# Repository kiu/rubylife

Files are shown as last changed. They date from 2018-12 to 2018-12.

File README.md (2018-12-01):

# rubylife
Show the world your ruby affection and live the [#BadgeLife](https://twitter.com/search?q=%23badgelife)!

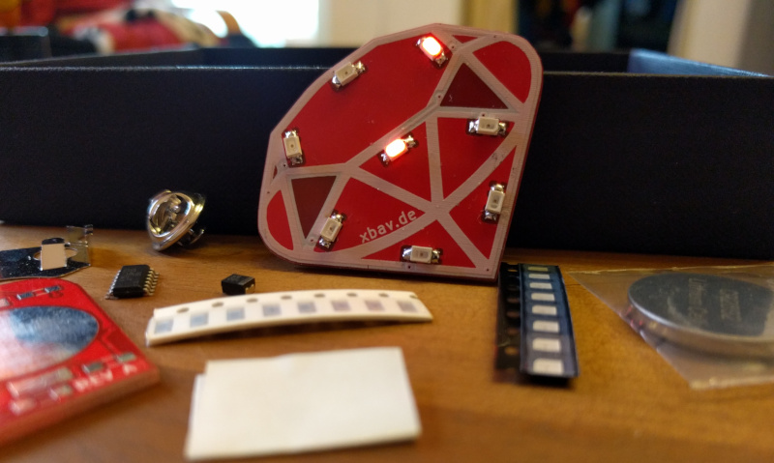
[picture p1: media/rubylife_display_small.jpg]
rubylife


# What does it do?
Besides being a stylish ruby pin, it can blink a few animations :)

# What do I need?
All you need is soldering gear (iron, tin, tweezers). Everything else is in the kit.

## I don't know how to solder!
It's easier than it looks, but a bit of help to kickstart your hardware adventure doesn't hurt. Ask your colleagues or friends for help. Or seek help in a [hackerspace](https://hackaday.io/hackerspaces) near you, they will love to teach you the ropes!

## Anything I need to know before I start?
Be aware that all parts - except for the resistors - have a polarity. Their orientation on the board is important.

Checkout this [reference](https://github.com/kiu/rubylife/raw/master/media/rubylife_polarity.jpg)!

## What is in the kit?

| Amount | Item |
| --- | ---- |
| 1 | Printed circuit board |
| 1 | Pre-programmed microcontroller |
| 8 | Red LED |
| 8 | Resistors |
| 1 | Capacitor |
| 1 | Battery Holder |
| 1 | Battery |
| 1 | Mounting pin |
| 1 | Glue dot |

A more detailed description can be found in the [Bill-Of-Materials](https://github.com/kiu/rubylife/raw/master/bom.pdf)

# I want to write my own software
Easy, but be aware that you need C skills to proceed :/

1. Setup an ATTiny development environment, e.g. [Atmel Studio](https://www.microchip.com/mplab/avr-support/atmel-studio-7)
2. Buy a hardware programmer. Make sure it supports TPI, e.g. [USBasp](https://www.fischl.de/usbasp/)
3. Hookup VCC, GND, TPIC, TPID and RES to your programmer and power it with 5 Volts
4. ???
5. Profit!

# Who created this?
[People](https://www.schoar.de/tinkering/rubylife/) from [xbAV](https://www.xbav.de) being passionate about hardware tinkering and the ruby community.

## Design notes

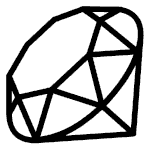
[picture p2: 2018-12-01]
hardware/kicad_mod_ruby.png

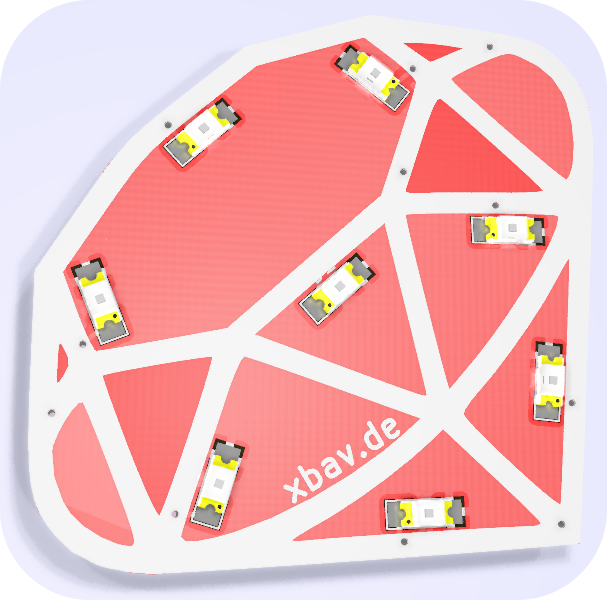
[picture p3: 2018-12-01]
hardware/kicad_rubylife_render_front.png

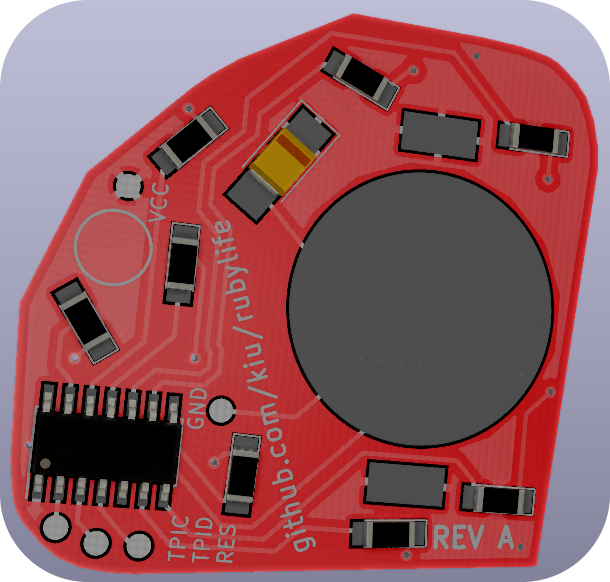
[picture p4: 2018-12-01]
hardware/kicad_rubylife_render_back.png

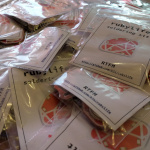
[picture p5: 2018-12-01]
media/rubylife_kit_pile_150x150.jpg

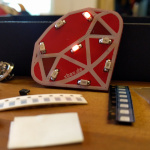
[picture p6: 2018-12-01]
media/rubylife_display_150x150.jpg

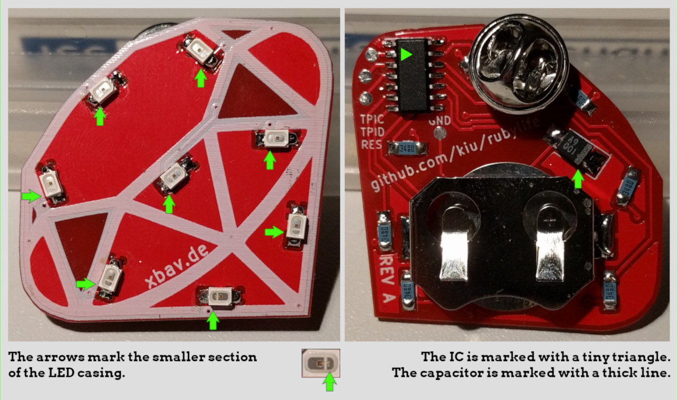
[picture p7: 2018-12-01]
media/rubylife_polarity.jpg

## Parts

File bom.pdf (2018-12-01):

BOM

Page 1

Symbol | Description | Req | +VAT | Price | Price (sum) | Price | Price (sum) | Provider | ID
| | | | MOQ 100 | | MOQ 50
U1 | ATTINY20 SOIC-14 | 1 | 19 | 0,41 € | 0,48 € | 0,44 € | 0,52 € | http://www.mouser.de | 556-ATTINY20-SSU
D1-8 | LED 1206 red 1100mcd 120° | 8 | 19 | 0,13 € | 1,21 € | 0,13 € | 1,21 € | http://www.mouser.de | 941-CLM3CRKWCUBVAAA3
R1-8 | Resistor 384R 1206 | 8 | 19 | 0,01 € | 0,06 € | 0,01 € | 0,09 € | http://www.mouser.de | 660-RK73H2BTTD3480F
C1 | Tantalum 100uF 6.3V B-Case | 1 | 19 | 0,25 € | 0,30 € | 0,27 € | 0,32 € | http://www.mouser.de | 647-F930J107KBA
BT1 | CR2032 Holder | 1 | 19 | 0,21 € | 0,25 € | 0,23 € | 0,28 € | http://www.mouser.de | 712-BAT-HLD-001
- | Butterfly Pin | 1 | 0 | 0,07 € | 0,07 € | 0,14 € | 0,14 € | http://www.amazon.de | B0734RD4GS
- | Glue dot | 1 | 0 | 0,06 € | 0,06 € | 0,13 € | 0,13 € | http://www.amazon.de | B00N6XASP0
- | CR2032 | 1 | 0 | 0,55 € | 0,55 € | 0,55 € | 0,55 € | http://www.amazon.de | B018S4PT0A
- | Zip Bag 80x120 | 1 | 0 | 0,06 € | 0,06 € | 0,12 € | 0,12 € | http://www.amazon.de | B07BF8MCCB
- | PCB 37x37 Red | 1 | 0 | 0,73 € | 0,73 € | 1,21 € | 1,21 €
SUM | SUM
3,77 € | 4,56 €
377,35 € | 228,16 €

http://www.seeedstudio.com

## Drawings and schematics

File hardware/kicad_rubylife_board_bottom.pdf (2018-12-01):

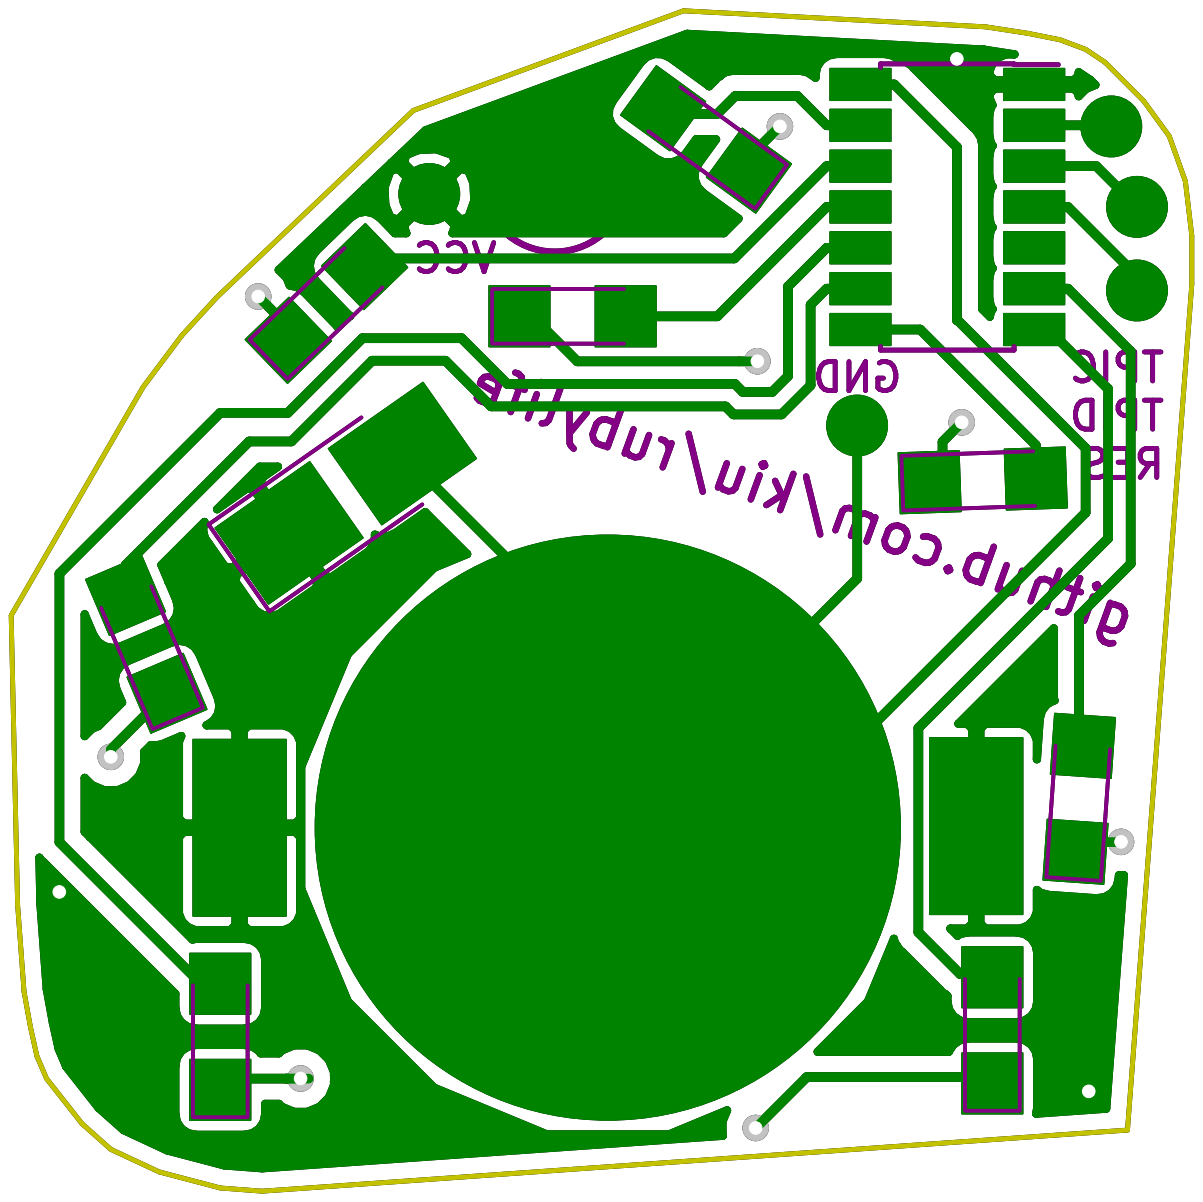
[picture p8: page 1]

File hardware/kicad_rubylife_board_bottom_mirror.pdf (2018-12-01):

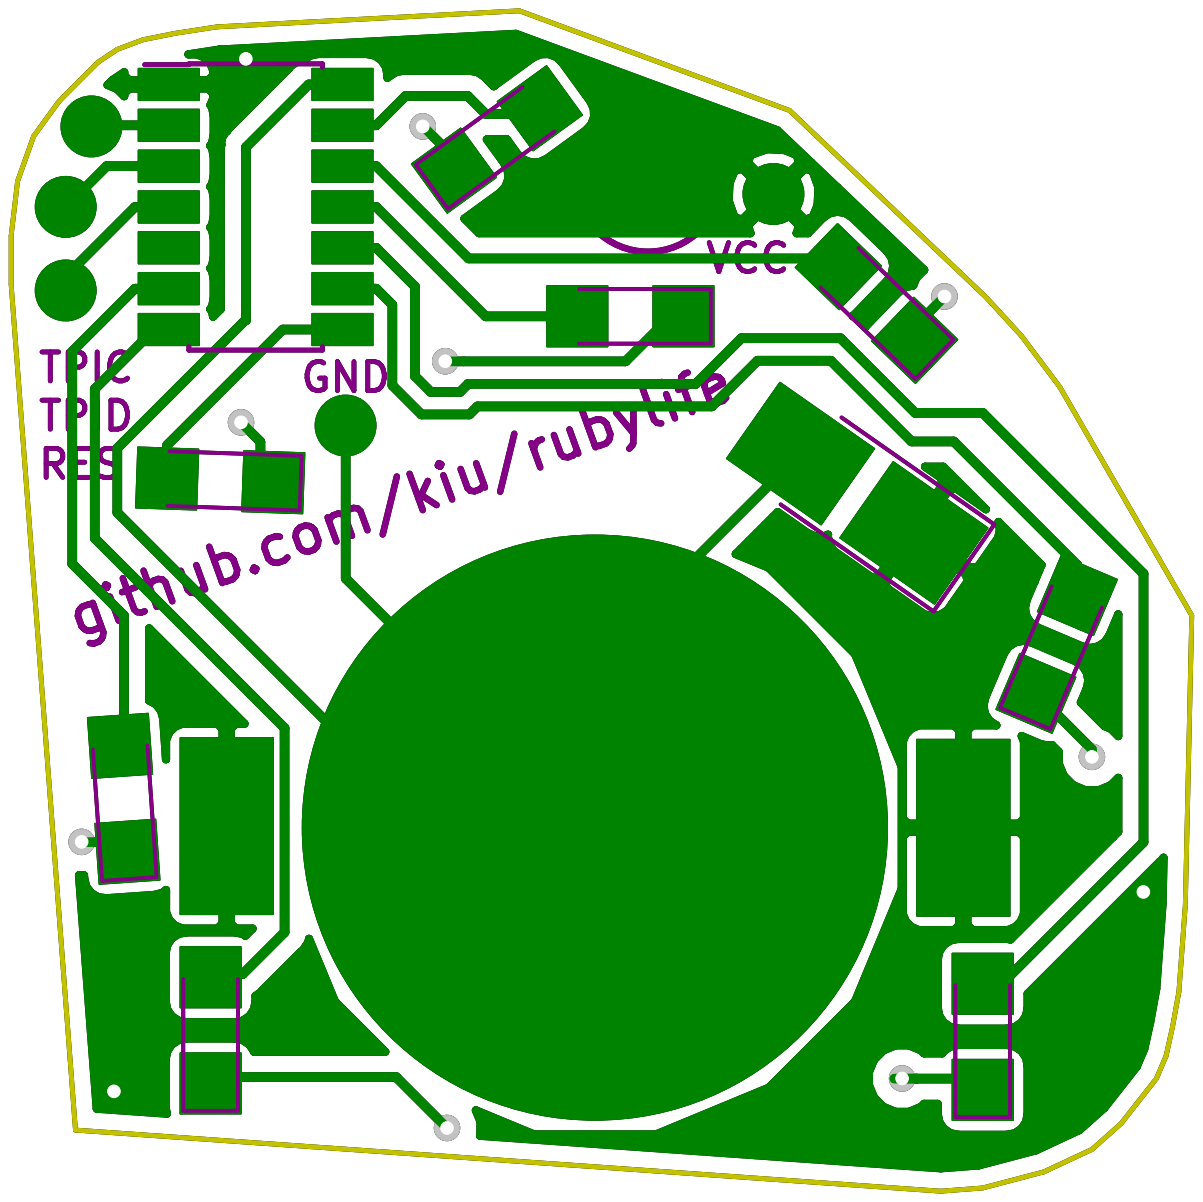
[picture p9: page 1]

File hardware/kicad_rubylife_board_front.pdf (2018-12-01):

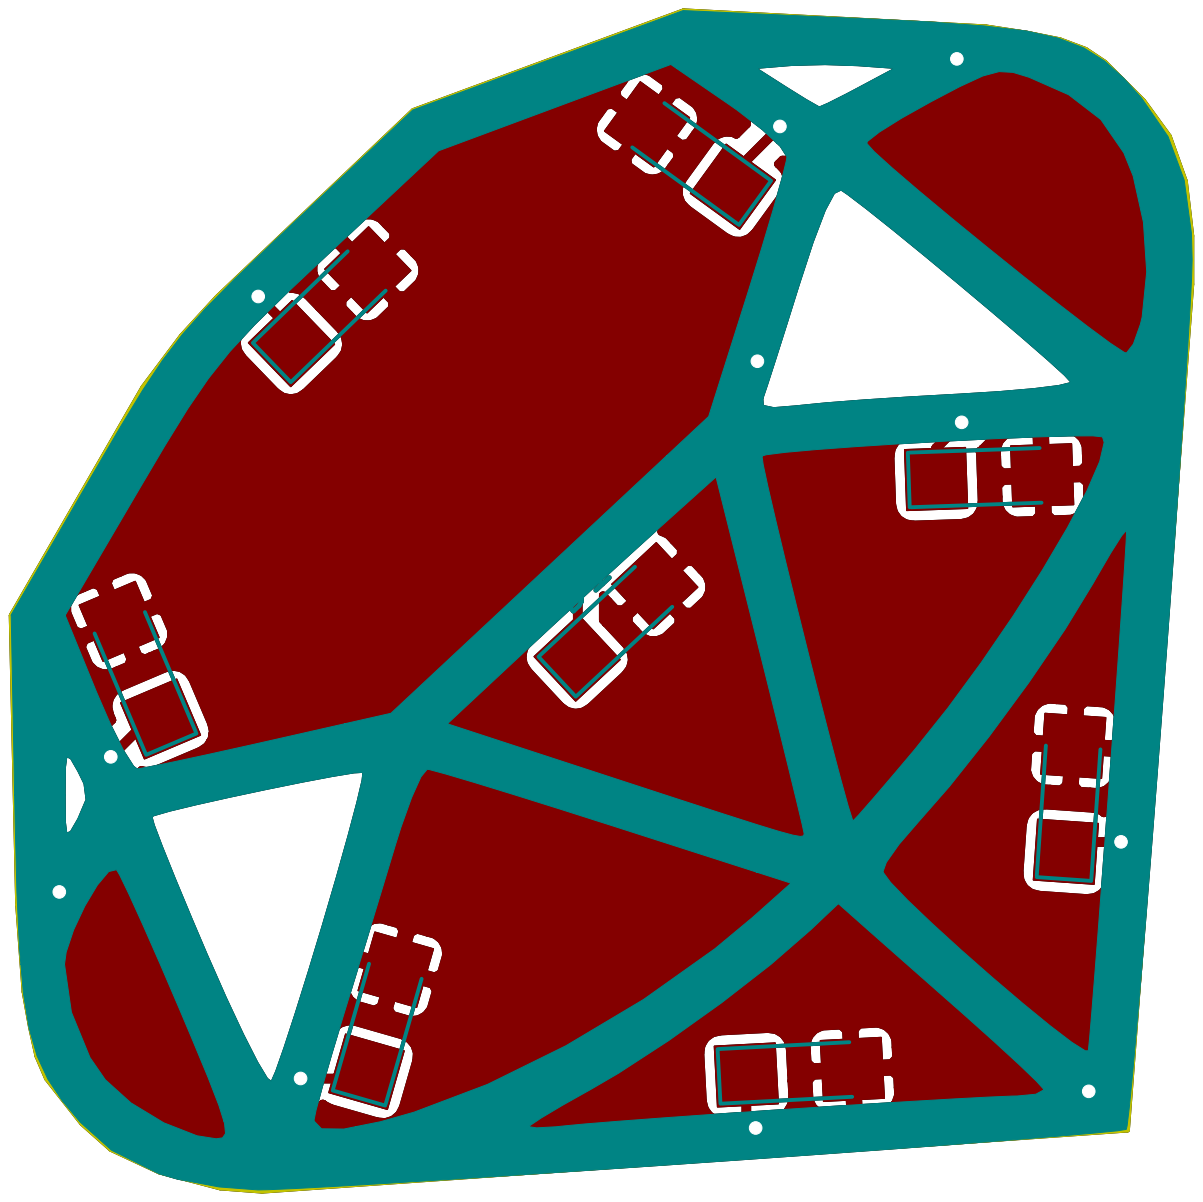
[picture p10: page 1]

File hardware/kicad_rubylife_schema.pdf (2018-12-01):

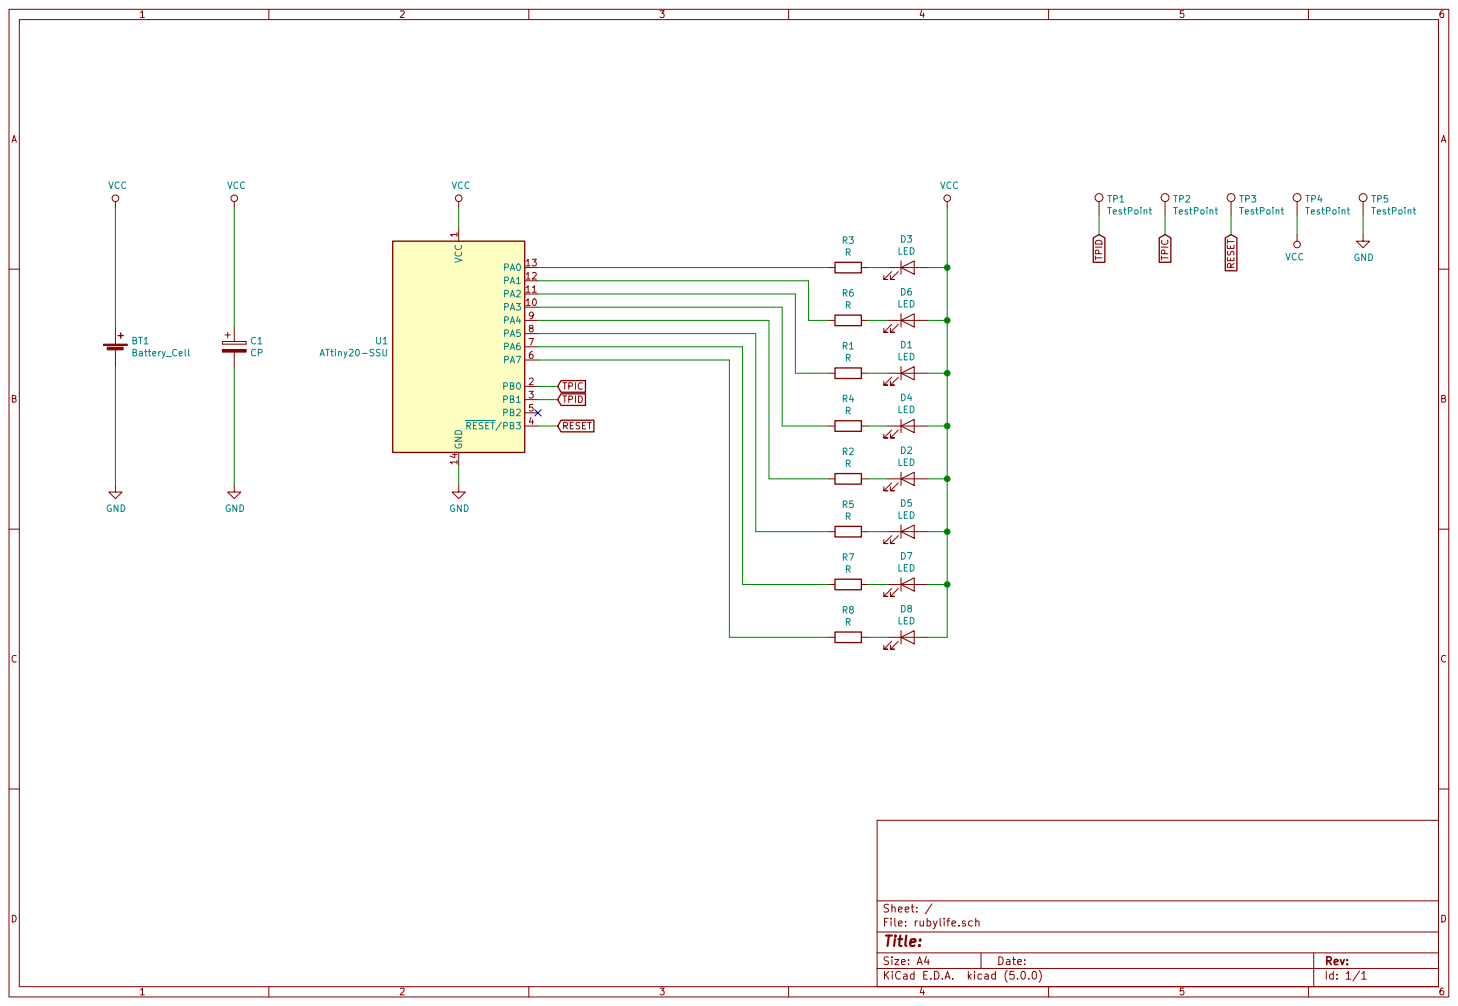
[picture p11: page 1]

File: rubylife.sch Sheet: /
Id: 1/1 Title:

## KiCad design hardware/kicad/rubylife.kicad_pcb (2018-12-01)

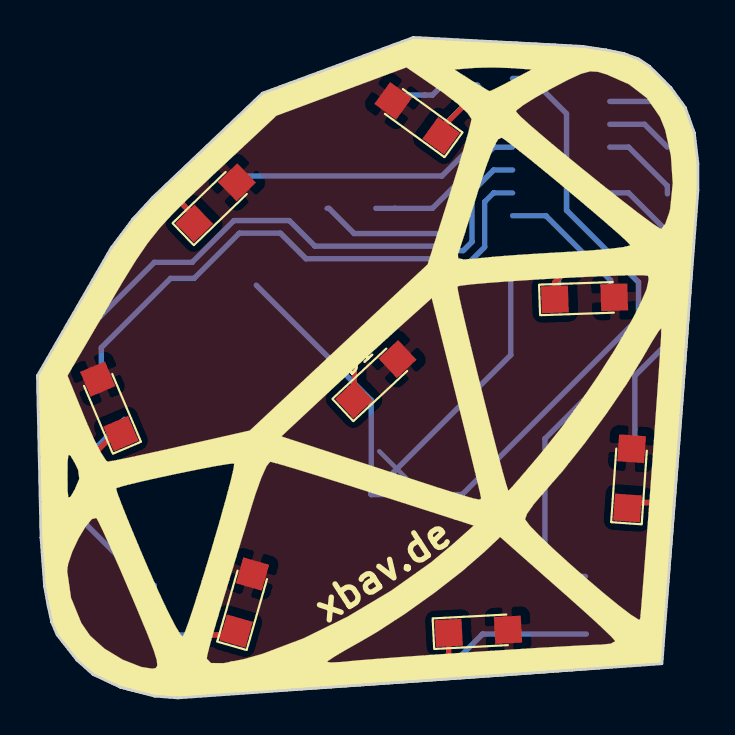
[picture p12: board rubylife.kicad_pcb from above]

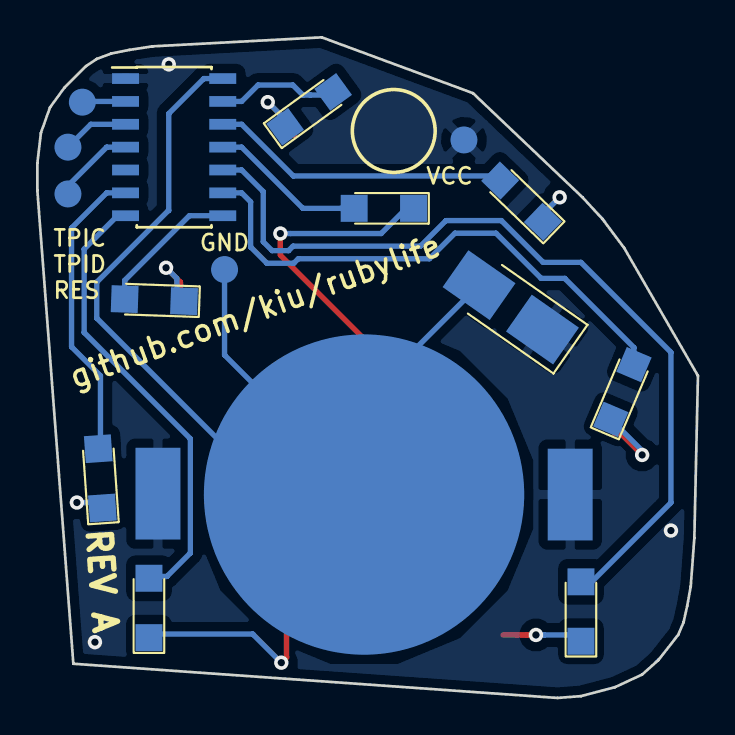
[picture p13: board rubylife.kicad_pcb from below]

Board: 2 copper layers, 36.7 x 36.7 mm, 24 parts (16 on the bottom side), 21 nets.

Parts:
BT1: Battery_Cell; CR2032 SMD
C1: CP; CP_Tantalum_Case-B_EIA-3528-21_Hand
D1, D2, D3, D4, D5, D6, D7, D8: LED; LED_1206
R1, R2, R3, R4, R5, R6, R7, R8: R; R_1206
TP1, TP2, TP3, TP4, TP5: TestPoint; Measurement_Point_Round-SMD-Pad_Small
U1: ATtiny20-SSU; SOIC-14_3.9x8.7mm_Pitch1.27mm

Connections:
GND: BT1.2, C1.2, TP5.1, U1.14
unnamed: D1.1, R1.1
unnamed: D2.1, R2.1
unnamed: D3.1, R3.1
unnamed: D4.1, R4.1
unnamed: D5.1, R5.1
unnamed: D6.1, R6.1
unnamed: D7.1, R7.1
unnamed: D8.1, R8.1
unnamed: R1.2, U1.11
unnamed: R2.2, U1.9
unnamed: R3.2, U1.13
unnamed: R4.2, U1.10
unnamed: R5.2, U1.8
unnamed: R6.2, U1.12
unnamed: R7.2, U1.7
unnamed: R8.2, U1.6
RESET: TP3.1, U1.4
TPIC: TP2.1, U1.2
TPID: TP1.1, U1.3
VCC: BT1.1, C1.1, D1.2, D2.2, D3.2, D4.2, D5.2, D6.2, D7.2, D8.2, TP4.1, U1.1

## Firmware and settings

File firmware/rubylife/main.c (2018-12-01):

/*
 * rubylife.c
 *
 * Created: 07.10.2018 01:20:25
 * Author : kiu
 */ 

#define F_CPU 4000000L
#define LED_COUNT 8

#define PWM_HIGH 0xE1
#define PWM_MIDDLE 0x37
#define PWM_LOW 0x14
#define PWM_OFF 0x00

#include <avr/io.h>
#include <avr/interrupt.h>
#include <avr/sleep.h>
#include <util/delay.h>
#include <stdlib.h>

volatile uint8_t pwm_led[LED_COUNT] = {0x00, 0x00, 0x00, 0x00, 0x00, 0x00, 0x00, 0x00};
volatile uint8_t pwm_i = 0;
uint8_t i;


ISR(TIM0_COMPA_vect) {
	asm("WDR");
	
	uint8_t pwm_out = 0x00;
	
	if (pwm_i >= pwm_led[0]) {
		pwm_out |= _BV(0);
	}
	if (pwm_i >= pwm_led[1]) {
		pwm_out |= _BV(1);
	}
	if (pwm_i >= pwm_led[2]) {
		pwm_out |= _BV(2);
	}
	if (pwm_i >= pwm_led[3]) {
		pwm_out |= _BV(3);
	}
	if (pwm_i >= pwm_led[4]) {
		pwm_out |= _BV(4);
	}
	if (pwm_i >= pwm_led[5]) {
		pwm_out |= _BV(5);
	}
	if (pwm_i >= pwm_led[6]) {
		pwm_out |= _BV(6);
	}
	if (pwm_i >= pwm_led[7]) {
		pwm_out |= _BV(7);
	}

	PORTA = pwm_out;

	pwm_i++;
}

ISR(WDT_vect) {
	WDTCSR |= _BV(WDIE);
}

void pwm_led_set(uint8_t idx, uint8_t val) {
	if (idx > LED_COUNT - 1) {
		return;
	}
	pwm_led[idx] = val;
}

uint8_t pwm_led_get(uint8_t idx) {
	if (idx > LED_COUNT - 1) {
		return 0;
	}
	return pwm_led[idx];
}

void pwm_fade_out() {
	uint8_t max = 0;

	for (i = 0; i < LED_COUNT; i++) {
		if (pwm_led[i] > max) {
			max = pwm_led[i];
		}
	}

	while (max > 0) {
		max--;

		for (i = 0; i < LED_COUNT; i++) {
			if (pwm_led[i] > max) {
				pwm_led[i] = max;
			}
		}
		
		_delay_us(500);
	}
}

void show_sparkle() {
	
	for (uint16_t j = 0; j < 1600; j++) {
		switch(rand() % 30) {
			case 0:
				pwm_led[rand() % 8] = PWM_HIGH;
				break;
			case 1:
			case 2:
				pwm_led[rand() % 8] = PWM_MIDDLE;
				break;
			case 3:
			case 4:
			case 5:
				pwm_led[rand() % 8] = PWM_LOW;
				break;
			default:
				pwm_led[rand() % 8] = PWM_OFF;
		}
		_delay_ms(5);
	}
	
}

void show_single() {
	
	for (uint8_t r = 0; r < 3; r++) {

		for (i = 0; i < PWM_HIGH; i++) {
			pwm_led[2] = i;
			_delay_ms(5);
		}

		for (i = PWM_HIGH; i > 0 ; i--) {
			pwm_led[2] = i;
			_delay_ms(5);
		}

	}

}

void show_swirl(uint8_t dir) {
	
	uint8_t order[] = {99, 99, 99, 99, 7, 5, 0, 1, 4, 3, 6, 7, 5, 0, 1, 4, 3, 6, 7, 5, 0, 1, 4, 3, 6, 7, 5, 0, 1, 4, 3, 6, 7, 5, 0, 1, 4, 3, 6, 7, 5, 0, 1, 4, 3, 6, 7, 5, 0, 1, 4, 3, 6, 7, 5, 0, 1, 4, 3, 6, 99, 99, 99, 99};
	uint8_t size = sizeof(order);
	uint8_t b;

	if (!dir) {
		for (i = 0; i < size; i++) {
			b = 0xFF;
			while (b > 0) {
				b--;
				if (i > 0 && 0xFF - b <= PWM_HIGH && 0xFF - b > pwm_led_get(order[i])) {
					pwm_led_set(order[i], 0xFF - b);
				}
				if (i > 1 && b >= PWM_MIDDLE && b < pwm_led_get(order[i - 1])) {
					pwm_led_set(order[i - 1], b);
				}
				if (i > 2 && b >= PWM_LOW && b < pwm_led_get(order[i - 2])) {
					pwm_led_set(order[i - 2], b);
				}
				if (i > 3 && b >= PWM_OFF && b < pwm_led_get(order[i - 3])) {
					pwm_led_set(order[i - 3], b);
				}
				
				_delay_us(400);
			}
		}
	} else {
		for (i = size - 1; i > 0; i--) {
			b = 0xFF;
			while (b > 0) {
				b--;
				if (i + 0 < size - 1 && 0xFF - b <= PWM_HIGH && 0xFF - b > pwm_led_get(order[i])) {
					pwm_led_set(order[i], 0xFF - b);
				}
				if (i + 1 < size - 1 && b >= PWM_MIDDLE && b < pwm_led_get(order[i + 1])) {
					pwm_led_set(order[i + 1], b);
				}
				if (i + 2 < size - 1 && b >= PWM_LOW && b < pwm_led_get(order[i + 2])) {
					pwm_led_set(order[i + 2], b);
				}
				if (i + 3 < size - 1 && b >= PWM_OFF && b < pwm_led_get(order[i + 3])) {
					pwm_led_set(order[i + 3], b);
				}
				
				_delay_us(400);
			}
		}
	}

}

void next() {
	pwm_fade_out();
	
	DDRA = 0x00;
	sleep_enable();
	sleep_mode(); // 8s
	sleep_mode(); // 8s
	sleep_mode(); // 8s	
	sleep_disable();
	DDRA = 0xFF;
}

int main(void) {
	
	CCP = 0xD8; // Set signature for privileged access
	WDTCSR = _BV(WDE);
	
	CCP = 0xD8; // Set signature for privileged access
	WDTCSR = _BV(WDIE) | _BV(WDP3) | _BV(WDP0);
		
	CCP = 0xD8; // Set signature for privileged access
	//CLKPSR = 0x00;	// 8Mhz
	CLKPSR = 0x01;		// 4Mhz
	//CLKPSR = 0x02;	// 2Mhz
	//CLKPSR = 0x03;	// 1Mhz

	DDRA = 0xFF; // PA0-PA7 are all outputs
	PORTA = 0xFF; // PA0-PA7 are all high --> LEDs are off
		
	PRR = _BV(PRADC) | _BV(PRSPI) | _BV(PRTWI) | _BV(PRTIM1); // Save power by disabling ADC, SPI, TWI and Timer1
	ACSRA = _BV(ACD); // Save power by disabling Analog Comparator
	
	// Setup TIMER0 used by PWM
	//TCCR0B |= _BV(CS02) | _BV(CS00);	// 1024
	TCCR0B |= _BV(CS02);				// 256
	//TCCR0B |= _BV(CS01) | _BV(CS00);	// 64	
	//TCCR0B |= _BV(CS01);				// 8
	TCCR0A |= _BV(WGM01); // CTC Mode	
	OCR0A = 0; // Match
	TIMSK |=_BV(OCIE0A); // Interrupt Match	

	srand(423);

	set_sleep_mode(SLEEP_MODE_PWR_DOWN);

	sei();

	while(1) {
		show_sparkle();
		next();
		
		show_swirl(0);
		next();
		
		show_single();
		next();
		
		show_swirl(1);
		next();
	}
}
